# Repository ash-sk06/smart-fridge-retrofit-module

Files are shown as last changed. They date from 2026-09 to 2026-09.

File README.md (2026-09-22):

<p align="center">
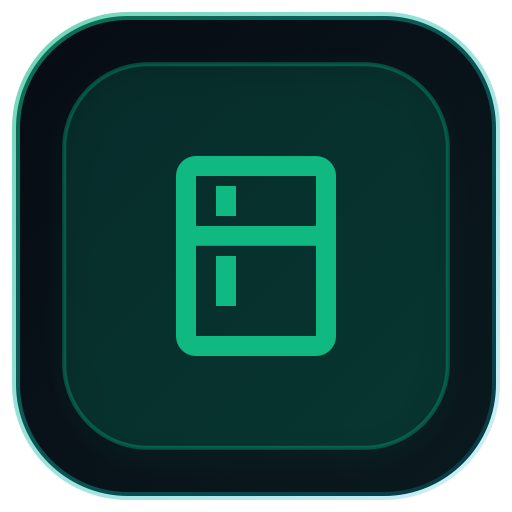
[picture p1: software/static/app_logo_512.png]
ChillSense Logo
  
</p>

# ChillSense — Smart Fridge Retrofit Module
### AI Refrigerator Retrofit Module Using Multi-Sensor Fusion & Cloud Vision for Food Inventory Management








---

## 📌 Overview

The **Smart Fridge Retrofit Module** (**ChillSense**) is a non-invasive, low-cost (₹2,000 – ₹3,000 INR / ~$25–$35 USD) hardware-software upgrade package designed to transform any conventional household refrigerator into an intelligent, cloud-connected inventory management appliance.

Commercial smart refrigerators retail at prohibitive price points ($2,000–$4,000 USD). This retrofit module achieves continuous liquid volume tracking inside opaque cartons, real-time shelf telemetry, condensation-free overhead image capture, and automated restocking notifications through **synchronized multi-sensor IoT fusion** and **Cloud YOLOv8 AI vision**.

---

## 🚀 Key Features

- **Anti-Fog Conical Camera Pod (`cad/`):**
  - Custom 3D-printable dual-part enclosure designed for 4°C humid refrigeration environments.
  - Features a 65° conical anti-fog optical baffle, internal flash isolation collar (eliminating optical lens flare), and magnetic mounting.
- **Embedded IoT Micro-Hub Firmware (`software/firmware/`):**
  - **ESP32-CAM (with Upgraded OV3660 3MP Sensor):** Door-switch interrupt triggered image capture with synchronized 100ms flash strobe, sending JPEG frames via HTTP POST to the cloud/server.
  - **ESP32 Sensor Hub (ESP32-WROOM-32 / ESP32-S2):** Samples dual HX711 24-bit differential ADCs across dedicated 5kg cantilever scale trays, DHT22 climate sensor (temperature & humidity), and MC-38 magnetic door reed switch.
- **Central Telemetry & Cloud Vision Engine (`software/`):**
  - Lightweight Python Flask backend with SQLite inventory audit trails and RESTful APIs.
  - **Cloud AI Vision:** Ultralytics YOLOv8n inference pipeline for item identification and bounding-box tagging.
  - Automated low-stock trigger and grocery reordering pipeline.
  - Cloud-ready architecture (deployable on Render, Railway, AWS, or local host).
- **Mobile Companion App (`mobile_app/`):**
  - Cross-platform Flutter application (Android/iOS) with industrial dark-theme HUD.
  - **Native Android Push Notifications:** Delivers heads-up sound & vibration alerts with item name and remaining volume when containers fall below 20%.
  - Dual-zone animated liquid fill gauge (Milk & Beverage).
  - 2×2 responsive telemetry metric grid (DHT22 climate, MC-38 door switch, HX711 shelf mass) optimized for mobile portrait view.
  - Built-in live interactive simulation controls for faculty demonstration.

---

## 📂 Repository Structure

```text
.
├── cad/                                # 3D CAD models & 3D printing specifications
│   ├── anti_fog_camera_pod.scad        # Parametric OpenSCAD design source
│   ├── camera_pod_main_body.stl        # 3D-printable camera housing
│   ├── camera_pod_back_lid.stl         # Snap-fit backplate with magnet wells
│   ├── camera_pod_3d_render.jpg        # Photorealistic CAD preview
│   ├── generate_stl.py                 # Automated STL build script
│   └── 3D_PRINTING_AND_SLICING_GUIDE.md# PETG/PLA slicer specifications
│
├── software/                           # Cloud backend server, APIs, and firmware
│   ├── server.py                       # Core Flask REST server & YOLOv8 CV pipeline
│   ├── requirements.txt                # Python dependencies
│   ├── run_server.sh                   # One-click startup script
│   ├── render.yaml & Procfile          # Cloud deployment configuration
│   ├── templates/                      # Web dashboard interface (HTML5 / Tailwind CSS)
│   └── firmware/                       # Embedded C++ Arduino firmware
│       ├── esp32_cam_strobe.ino        # ESP32-CAM strobe & capture client
│       └── esp32_sensor_hub.ino        # ESP32 multi-sensor telemetry client
│
├── mobile_app/                         # Flutter companion mobile application (ChillSense)
│   ├── lib/                            # Application source (Layered MVVM Architecture)
│   │   ├── models/                     # Telemetry, inventory & sensor data models
│   │   ├── services/                   # HTTP REST API client & native notifications
│   │   ├── widgets/                    # Responsive telemetry grid & liquid gauges
│   │   └── screens/                    # Dashboard, sensors & live review demo
│   ├── pubspec.yaml                    # Dart package dependencies
│   ├── ChillSense-v1.0-release.apk     # Production Android release APK
│   └── android/                        # Native Android build & notification manifests
│
└── README.md                           # Master project documentation
```

---

## 🛠️ Quick Start Guide

### 1. Run the Backend & Cloud Vision Server
```bash
cd software
python3 -m venv venv
source venv/bin/activate
pip install -r requirements.txt
python server.py
# Server runs at http://0.0.0.0:5050 with live Web HUD
```

### 2. Build or Install the Mobile App
```bash
cd mobile_app
flutter pub get
flutter run
# Or build production APK:
flutter build apk --release
```
*A pre-compiled production APK is also provided in `mobile_app/ChillSense-v1.0-release.apk`.*

### 3. 3D Print the Enclosure
Open `cad/anti_fog_camera_pod.scad` in OpenSCAD or slice the pre-rendered STL files:
- `cad/camera_pod_main_body.stl`
- `cad/camera_pod_back_lid.stl`
- Recommended material: **PETG** (moisture and condensation resistant in 4°C environments).

### 4. Flash Embedded Firmware
1. Open `software/firmware/esp32_sensor_hub.ino` and `software/firmware/esp32_cam_strobe.ino` in Arduino IDE.
2. Configure local Wi-Fi credentials and the server host address.
3. Flash to the respective ESP32 boards.

---

## 📜 Intellectual Property Framework

- **Inventive Step:** Event-Gated Differential Gravimetric Sampling & Anti-Fog Optical Enclosure for Retrofit Smart Refrigeration.
- **Core Problem Solved:** Eliminates load-cell thermal resistance drift across refrigeration temperature cycles through door-transit baseline calibration, while accurately quantifying fluid depletion inside opaque packaging without internal food immersion probes.
- Drafted in accordance with the **Indian Patents Act, 1970 (Form 2)**.

---

## 👥 Authors & Academic Context
Developed as an engineering capstone project focusing on sustainable embedded systems, Cloud AI vision, and household food waste reduction.

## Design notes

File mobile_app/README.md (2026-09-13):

# Smart Fridge Retrofit: Mobile Companion App (Flutter)
**Project:** AI Refrigerator Retrofit Module Using Multi-Sensor Fusion  
**Framework:** Flutter (Material 3)  
**Supported Platforms:** Android, iOS, Web (Chrome)

---

## 1. Features Overview

* **Real-Time Dual-Zone Fill Gauges:** Live animated liquid gradient bars showing milliliters ($ml$) and percentage ($%$) remaining for milk (Zone 1) and orange juice (Zone 2).
* **Dynamic Low-Stock Warnings:** Color-coded indicators:
  * **Green (Optimal):** $\ge 45\%$ fill
  * **Amber (Moderate):** $20\% - 44\%$ fill
  * **Red (Low Stock):** $< 20\%$ fill (triggers auto-shopping list insertion)
* **Live Environmental Telemetry:** Real-time monitoring of internal fridge temperature ($^\circ\text{C}$), relative humidity ($\% \text{RH}$), and door state (`OPEN` / `CLOSED`).
* **Overhead Vision AI Feed:** Displays the latest snapshot taken by the ESP32-CAM when the door was last closed, along with YOLOv8 detection tags (`bottle (Dairy)`, etc.).
* **Smart Automated Grocery List:** Automatically populates when liquid drops below $20\%$. Features interactive checkboxes to cross off items while shopping.
* **Faculty Review Demo Sandbox:** Floating action button with one-tap simulated events ("Pour 150ml Milk", "Toggle Door Event", "Trigger Low Stock Alert") to demonstrate dynamic UI updates during viva/reviews even without hardware powered on.

---

## 2. Quick Start: Running the App

### Step 1: Start Your Flask Backend on Your Laptop
In your terminal, launch the server:
```bash
cd "/Users/ashwathsathish/Library/Mobile Documents/com~apple~CloudDocs/AI Refridgerator Retrofit Module/software"
python3 server.py
```
Find your laptop's local IP address:
* **macOS / Linux:** Run `ifconfig | grep "inet "` (look for `192.168.x.x` or `10.x.x.x`).
* **Windows:** Run `ipconfig` (look for `IPv4 Address`).

### Step 2: Open & Run the Flutter App
Make sure your phone and laptop are on the **same Wi-Fi network or Mobile Hotspot**.

#### Option A: Run Directly on Your Android Phone (USB Debugging)
1. Enable **Developer Options** and **USB Debugging** on your Android phone.
2. Connect your phone to your laptop via USB cable.
3. Open a terminal in the `mobile_app/` folder:
   ```bash
   cd mobile_app
   flutter pub get
   flutter run
   ```
4. Once the app launches on your phone, tap the **Settings icon** (top right) and enter your laptop's IP address (e.g. `192.168.1.105:5000`).

#### Option B: Run in Chrome / Browser (Zero Phone Setup)
If you don't have an Android device plugged in, you can run the app directly in your desktop browser:
```bash
cd mobile_app
flutter pub get
flutter run -d chrome
```

#### Option C: Build the Standalone Android APK (To Share With Teammates)
To generate an installable `.apk` file:
```bash
cd mobile_app
flutter build apk --release
```
The installable APK will be created at:  
`mobile_app/build/app/outputs/flutter-apk/app-release.apk`  
You can send this APK to your teammates via WhatsApp or Google Drive and install it on any Android phone!

---

## 3. Directory Structure

```
mobile_app/
├── pubspec.yaml               # Flutter package configuration
├── README.md                  # This build & user guide
└── lib/
    ├── main.dart              # App entry point with Material 3 theme
    ├── models/
    │   └── inventory_model.dart  # Parsers for inventory, telemetry & shopping list
    ├── services/
    │   └── api_service.dart      # HTTP REST client communicating with Flask
    ├── widgets/
    │   ├── liquid_gauge_card.dart  # Animated liquid progress bar & metrics
    │   ├── telemetry_header.dart   # Live door, temp & humidity status
    │   ├── shopping_list_card.dart # Automated grocery list with checkboxes
    │   └── camera_vision_card.dart # ESP32-CAM overhead photo & YOLO tags
    └── screens/
        └── home_screen.dart       # Main dashboard with auto-polling & demo sandbox
```

---

## 4. Viva / Review Demonstration Script

When presenting to your faculty guide:
1. **Show the live connection:** Point out the green **"ESP32 HUB LIVE"** pill and the real-time temperature ($4.1^\circ\text{C}$).
2. **Demonstrate liquid depletion:** 
   * Lift a carton off the dual load-cell tray (or tap **"Pour 150ml Milk"** in the Demo Sandbox).
   * Within 2 seconds, watch the **liquid gauge drop** from $1000\text{ ml}$ to $850\text{ ml}$ on your phone in real-time.
3. **Demonstrate the automated trigger:**
   * Tap **"Trigger Low Stock Alert (< 20%)"**.
   * Show how the gauge turns **red**, the status changes to `LOW STOCK`, and the item **instantly appears on the Smart Shopping List** at the bottom of the screen.
4. **Demonstrate the door alarm:**
   * Open the mock fridge door (or tap **"Toggle Door Event"**).
   * Show the header flash yellow/red: **`DOOR OPEN`**.

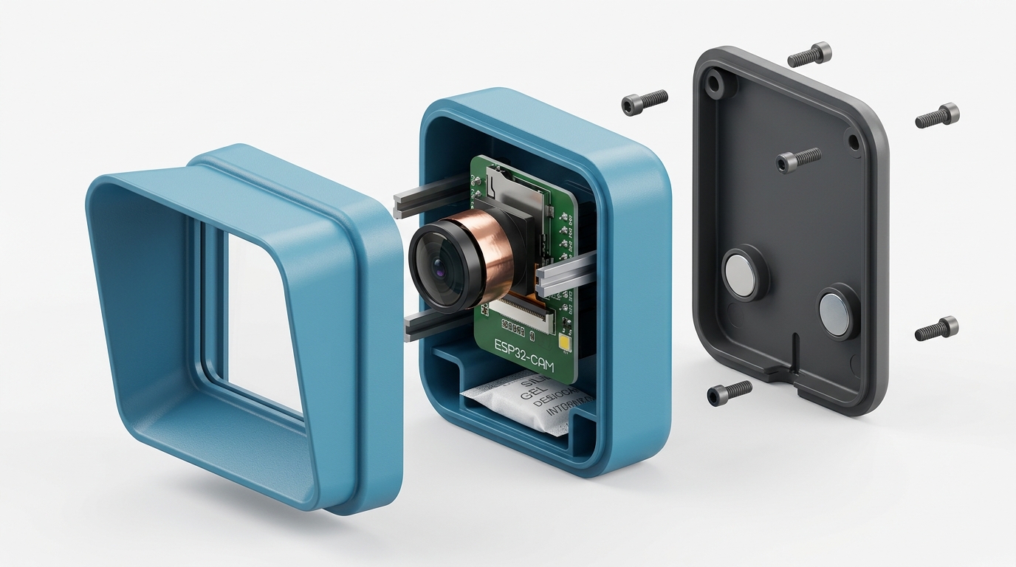
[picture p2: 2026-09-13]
cad/camera_pod_3d_render.jpg

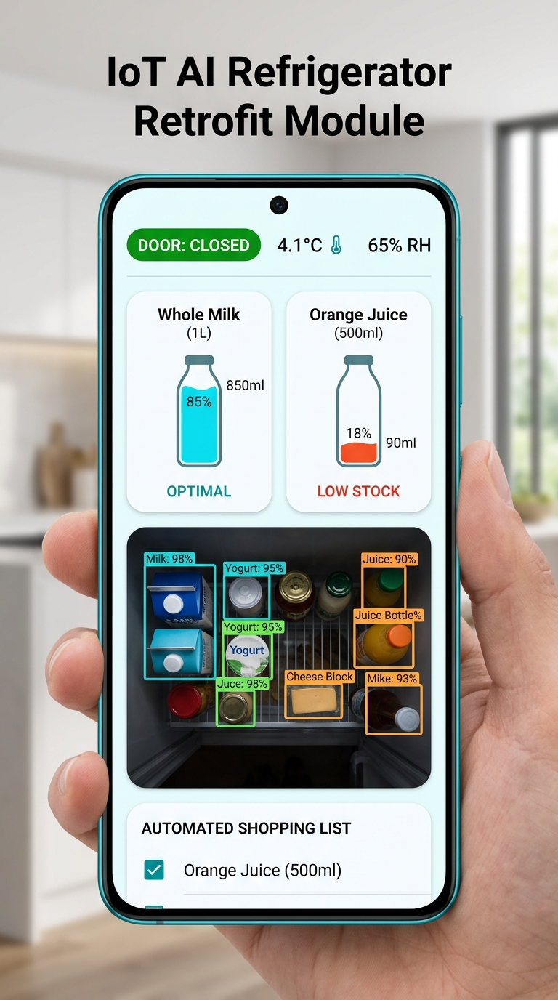
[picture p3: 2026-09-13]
mobile_app/mobile_app_ui_mockup.jpg

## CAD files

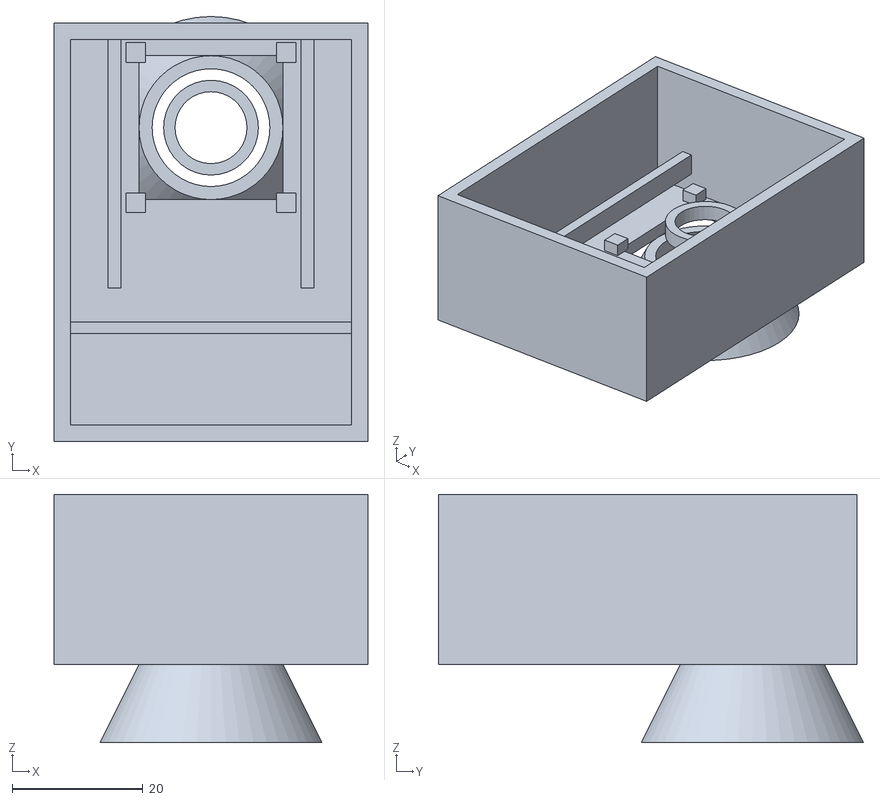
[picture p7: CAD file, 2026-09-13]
cad/camera_pod_main_body.stl
48.0 x 65.0 x 38.0

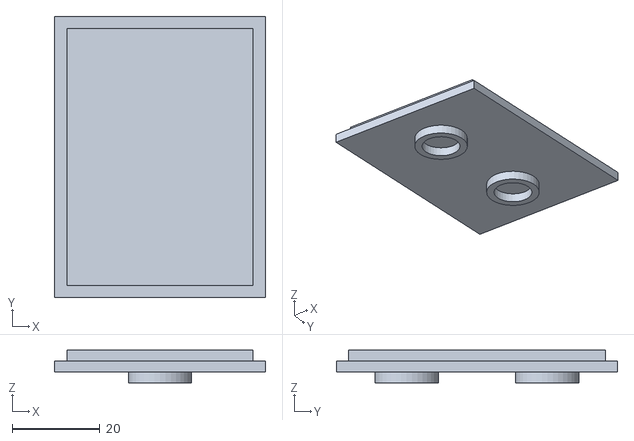
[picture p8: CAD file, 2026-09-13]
cad/camera_pod_back_lid.stl
48.0 x 64.0 x 7.50

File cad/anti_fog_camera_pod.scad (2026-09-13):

// =============================================================================
// AI REFRIGERATOR RETROFIT MODULE: 2-PART ANTI-FOG OPTIMIZED CAMERA POD
// Project: Dual-Zone Multi-Sensor Food Inventory System
// Target Hardware: AI-Thinker ESP32-CAM (OV2640 Module)
// Optical Upgrades:
//   1. 65-Degree Conical Flared Baffle (Zero Corner Vignetting / No Cut-Off)
//   2. Internal Optical Isolation Collar (Zero Flash LED Glare Bleed / No Milky Glare)
//   3. Retains Parasitic Heat Channel (Patent Claim 3) & Desiccant Bay
// =============================================================================

$fn = 60; // Smooth circular curves for 3D printing

// -----------------------------------------------------------------------------
// USER CONFIGURATION / DIMENSIONAL PARAMETERS (All dimensions in mm)
// -----------------------------------------------------------------------------
wall_th = 2.5;                // Structural wall thickness
box_w = 48.0;                 // Outer width
box_h = 64.0;                 // Outer height
box_d = 26.0;                 // Outer depth of cavity body

// Optical Aperture & Conical Anti-Fog Baffle
baffle_len = 12.0;            // 12mm forward extension for stagnant dead-air zone
baffle_base_id = 18.0;        // Inner diameter at optical window
baffle_mouth_id = 30.0;       // Flared inner diameter at mouth (accommodates 66° FOV cone)
baffle_wall = 2.0;            // Wall thickness of the baffle cone
lens_y_offset = 16.0;         // Offset from top edge to camera optical center

// Internal Optical Isolation Collar (Isolates Lens from Flash LED)
collar_id = 11.0;             // Inner diameter (clears 8.5mm OV2640 lens)
collar_od = 14.5;             // Outer diameter (physically blocks adjacent flash LED)
collar_h = 2.8;               // Extends backward to meet OV2640 sensor face

// Acrylic Optical Window Retention Pocket (Internal)
window_w = 26.0;              // Square pocket for 25x25mm acrylic square (+1mm clearance)
window_h = 26.0;              // Square pocket height
window_th = 2.2;              // Pocket depth for standard 2.0mm acrylic pane

// ESP32-CAM Module (AI-Thinker Standard: 27.0mm x 40.5mm)
pcb_w = 27.5;                 // PCB slot width (+0.5mm slide clearance)
pcb_th = 1.6;                 // Standard FR4 PCB thickness
pcb_h = 40.5;                 // PCB height

// Desiccant Bay (Silica Gel 1g-2g Pouch)
desiccant_w = 40.0;
desiccant_h = 14.0;
desiccant_d = 18.0;

// Back Lid & Magnetic Retrofit Mounts
lid_th = 2.5;
magnet_diam = 10.3;           // Sized for standard 10mm Neodymium disc magnets
magnet_depth = 2.2;           // Depth for 2mm thick disc magnets
cable_diam = 4.5;             // Micro-USB / power cable diameter

// -----------------------------------------------------------------------------
// SELECT WHAT TO RENDER (Change number to render specific part)
// 1 = Complete 2-Part Exploded Assembly (Visualization)
// 2 = Part 1: Main Housing with Flared Baffle & Light Collar (Print 1x)
// 3 = Part 2: Back Lid with Magnetic Mounts (Print 1x)
// -----------------------------------------------------------------------------
RENDER_PART = 1;

if (RENDER_PART == 1) {
    exploded_assembly_2part();
} else if (RENDER_PART == 2) {
    part1_main_housing_integrated();
} else if (RENDER_PART == 3) {
    part2_back_lid();
}

// =============================================================================
// PART 1: MAIN HOUSING WITH CONICAL BAFFLE & OPTICAL ISOLATION COLLAR
// =============================================================================
module part1_main_housing_integrated() {
    union() {
        // --- Main Housing Body ---
        difference() {
            // Outer Rounded Box
            hull() {
                translate([2, 2, 0]) cylinder(r=2, h=box_d);
                translate([box_w - 2, 2, 0]) cylinder(r=2, h=box_d);
                translate([box_w - 2, box_h - 2, 0]) cylinder(r=2, h=box_d);
                translate([2, box_h - 2, 0]) cylinder(r=2, h=box_d);
            }

            // Main Internal Cavity
            translate([wall_th, wall_th, wall_th])
                cube([box_w - 2 * wall_th, box_h - 2 * wall_th, box_d]);

            // Optical Aperture Through Front Face
            translate([box_w / 2, box_h - lens_y_offset, -1])
                cylinder(d=baffle_base_id, h=wall_th + 2);

            // Acrylic Window Retention Recess (Inside front wall: 26x26x2.2mm)
            translate([(box_w - window_w) / 2, (box_h - lens_y_offset) - window_h / 2, wall_th - window_th + 0.01])
                cube([window_w, window_h, window_th + 0.1]);

            // Parasitic Thermal Conduction Channel (Claim 3)
            translate([(box_w - 12) / 2, (box_h - lens_y_offset) - window_h / 2 - 10, wall_th - 1.2])
                cube([12, 12, 1.5]);

            // Rear Lid Inset Lip Chamfer
            translate([wall_th - 0.4, wall_th - 0.4, box_d - 2.5])
                cube([box_w - 2 * wall_th + 0.8, box_h - 2 * wall_th + 0.8, 3.0]);
        }

        // --- Integrated 65-Degree Conical Anti-Fog Baffle (Monolithic) ---
        // Flares outward from 18mm at the glass to 30mm at the mouth
        translate([box_w / 2, box_h - lens_y_offset, -baffle_len])
            difference() {
                // Outer tapered cone (63° angle from horizontal — 100% printable with NO supports)
                cylinder(d1=baffle_mouth_id + 2 * baffle_wall, d2=baffle_base_id + 2 * baffle_wall, h=baffle_len + 0.05);
                
                // Conical optical tunnel through-hole
                translate([0, 0, -1])
                    cylinder(d1=baffle_mouth_id, d2=baffle_base_id, h=baffle_len + 3);
            }

        // --- Internal Optical Isolation Collar (Blocks Flash LED Bleed) ---
        // Extends backwards from the acrylic window to hug the OV2640 lens barrel
        translate([box_w / 2, box_h - lens_y_offset, wall_th + window_th - 0.1])
            difference() {
                cylinder(d=collar_od, h=collar_h);
                translate([0, 0, -0.5])
                    cylinder(d=collar_id, h=collar_h + 1);
            }

        // --- Internal ESP32-CAM Guide Rails ---
        rail_x_left = (box_w - pcb_w) / 2 - 2.0;
        rail_x_right = (box_w + pcb_w) / 2;
        rail_y_start = box_h - wall_th - pcb_h - 1.0;
        rail_z_pos = wall_th + window_th + 2.0; // Keeps OV2640 lens 2mm behind acrylic

        difference() {
            union() {
                // Left Guide Rail
                translate([rail_x_left, rail_y_start, rail_z_pos - 1])
                    cube([2.0, pcb_h, 5.0]);
                // Right Guide Rail
                translate([rail_x_right, rail_y_start, rail_z_pos - 1])
                    cube([2.0, pcb_h, 5.0]);

                // Bottom Desiccant Bay Separator Rib
                translate([wall_th, wall_th + desiccant_h, wall_th])
                    cube([box_w - 2 * wall_th, 1.8, 12.0]);
            }
            // Slot for PCB to slide into smoothly
            translate([(box_w - pcb_w) / 2, rail_y_start - 1, rail_z_pos])
                cube([pcb_w, pcb_h + 2, pcb_th + 0.4]);
            
            // Air circulation cutout in desiccant rib
            translate([box_w / 2 - 8, wall_th + desiccant_h - 1, wall_th])
                cube([16, 4, 8]);
        }
    }
}

// =============================================================================
// PART 2: BACK LID WITH MAGNETIC RETROFIT MOUNTS & CABLE STRAIN RELIEF
// =============================================================================
module part2_back_lid() {
    difference() {
        union() {
            hull() {
                translate([2, 2, 0]) cylinder(r=2, h=lid_th);
                translate([box_w - 2, 2, 0]) cylinder(r=2, h=lid_th);
                translate([box_w - 2, box_h - 2, 0]) cylinder(r=2, h=lid_th);
                translate([2, box_h - 2, 0]) cylinder(r=2, h=lid_th);
            }

            translate([wall_th + 0.25, wall_th + 0.25, lid_th])
                cube([box_w - 2 * wall_th - 0.5, box_h - 2 * wall_th - 0.5, 2.5]);
        }

        // Dual 10mm Neodymium Magnet Recesses
        translate([box_w / 2, box_h * 0.28, -0.1])
            cylinder(d=magnet_diam, h=magnet_depth);
        translate([box_w / 2, box_h * 0.72, -0.1])
            cylinder(d=magnet_diam, h=magnet_depth);

        // Optional M3 Countersunk Screw Holes
        translate([box_w / 2, box_h * 0.28, -1])
            cylinder(d=3.4, h=lid_th + 5);
        translate([box_w / 2, box_h * 0.72, -1])
            cylinder(d=3.4, h=lid_th + 5);
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

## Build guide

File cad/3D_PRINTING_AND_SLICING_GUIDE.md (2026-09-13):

# 3D Printing & Assembly Guide: 2-Part Anti-Fog Camera Pod
**Project:** AI Refrigerator Retrofit Module Using Multi-Sensor Fusion  
**Target Hardware:** AI-Thinker ESP32-CAM (OV2640 Sensor)  
**Location:** [`cad/`](file:///Users/ashwathsathish/Library/Mobile%20Documents/com~apple~CloudDocs/AI%20Refridgerator%20Retrofit%20Module/cad/)

---

## 1. File Inventory (Strictly 2 Parts - Optically Optimized)

| File | Description | Material & Quantity |
| :--- | :--- | :---: |
| [**`camera_pod_main_body.stl`**](file:///Users/ashwathsathish/Library/Mobile%20Documents/com~apple~CloudDocs/AI%20Refridgerator%20Retrofit%20Module/cad/camera_pod_main_body.stl) | **Part 1:** Main housing with **$65^\circ$ conical flared baffle** (zero corner vignetting), **internal optical isolation collar** (stops flash LED bleed), $25\times25\text{ mm}$ acrylic pocket, ESP32 slide rails, and desiccant bay. | PLA / PETG (1x) |
| [**`camera_pod_back_lid.stl`**](file:///Users/ashwathsathish/Library/Mobile%20Documents/com~apple~CloudDocs/AI%20Refridgerator%20Retrofit%20Module/cad/camera_pod_back_lid.stl) | **Part 2:** Snap-fit rear cover with dual $10\text{ mm}$ Neodymium magnet sockets and S-curve cable strain relief. | PLA / PETG (1x) |
| [**`anti_fog_camera_pod.scad`**](file:///Users/ashwathsathish/Library/Mobile%20Documents/com~apple~CloudDocs/AI%20Refridgerator%20Retrofit%20Module/cad/anti_fog_camera_pod.scad) | Parametric OpenSCAD source file with 3D exploded assembly view. | Source |
| [**`generate_stl.py`**](file:///Users/ashwathsathish/Library/Mobile%20Documents/com~apple~CloudDocs/AI%20Refridgerator%20Retrofit%20Module/cad/generate_stl.py) | Python script to regenerate binary STLs directly. | Script |

---

## 2. 3D Slicer Settings (Cura / PrusaSlicer / Bambu Studio)

Both parts are engineered to print with **ZERO supports (0% supports needed)**.

```
┌────────────────────────────────────────────────────────────────────────┐
│                        RECOMMENDED SLICE PROFILE                       │
├─────────────────────────┬──────────────────────────────────────────────┤
│ Material                │ PETG (Preferred for cold/moisture) or PLA    │
│ Layer Height            │ 0.20 mm (Standard)                           │
│ Wall Line Count (Perim) │ 3 to 4 walls (≥ 1.2 mm solid perimeter)      │
│ Top / Bottom Layers     │ 4 top / 4 bottom layers                      │
│ Infill Density          │ 20%                                          │
│ Infill Pattern          │ Gyroid or Grid                               │
│ Print Speed             │ 50 mm/s                                      │
│ Supports                │ NONE (Disabled - 0% supports needed)         │
│ Build Plate Adhesion    │ Skirt (or 3mm Brim if bed adhesion is weak)  │
│ Bed Temperature         │ PLA: 60°C | PETG: 75°C - 80°C                │
│ Nozzle Temperature      │ PLA: 205°C | PETG: 235°C - 240°C             │
└─────────────────────────┴──────────────────────────────────────────────┘
```

### Print Orientation by Part:
1. **`camera_pod_main_body.stl`**: Place flat on its front face (baffle tube rim resting down on the build plate).
2. **`camera_pod_back_lid.stl`**: Place flat with the exterior face down on the bed.

### Print Statistics:
* **Total Filament Weight:** ~32 grams (~₹25 INR of filament).
* **Total Print Time:** ~1 hour 15 minutes on an Ender-3; ~25 minutes on a Bambu / K1.

---

## 3. Physical Assembly Steps

```
Step 1: Drop in Acrylic Window (25x25x2mm) from inside into molded pocket.
Step 2: Attach Foil Thermal Ribbon to ESP32 RF shield & route to window edge.
Step 3: Slide ESP32-CAM PCB into internal guide rails (lens 2mm behind window).
Step 4: Place 1g Silica Gel Pouch in the bottom bay.
Step 5: Press 2x 10mm Neodymium Magnets into back lid & snap lid shut.
Step 6: Buff outer acrylic face with half a drop of dish soap (surfactant film).
```

### Detailed Assembly:
1. **Optical Window:** Cut a $25\text{ mm} \times 25\text{ mm}$ square from 2.0mm clear acrylic (or scrap CD jewel case). Clean with alcohol, drop into the internal pocket behind the baffle, and seal edges with 2 drops of hot glue or silicone.
2. **Parasitic Heat Conductor (Claim 3):** Tape a strip of folded kitchen aluminum foil (or copper tape) to the ESP32's silver metal shield. Route it to touch the edge of the acrylic pane.
3. **Slide Board In:** Slide the ESP32-CAM (27.0mm wide) into the molded rails. The OV2640 lens sits centered directly behind the optical aperture.
4. **Desiccant:** Drop a 1g silica gel sachet into the lower compartment.
5. **Magnetic Mount:** Press two $10\text{ mm} \times 2\text{ mm}$ Neodymium magnets into the back lid sockets. Route the power cable through the strain-relief slot and press the lid shut!

---

## 4. Outer Hydrophilic Coating Application

Before sticking the pod inside the refrigerator:
1. Put half a drop of liquid dish soap (**Vim / Pril / Colin**) onto the outer face of the acrylic window (inside the baffle cone).
2. Spread evenly with a cotton bud. Let dry for 60 seconds.
3. Buff vigorously with a clean, dry microfiber cloth until completely transparent.
4. Water condensation will now form a flat transparent liquid sheet (contact angle $< 10^\circ$) instead of scattering droplets.

---

## 5. Critical Lens Macro Focus Adjustment (25 cm Shelf Height)

> [!IMPORTANT]
> **Why this is necessary:** All stock OV2640 modules from the factory are pre-focused at **1 meter to infinity**. At the 22–25 cm distance inside a refrigerator, the food cartons and labels will be slightly blurry unless you perform this 10-second adjustment:

1. Look at the threaded circular lens barrel on the OV2640 sensor. There is a tiny dot of yellow glue locking the thread.
2. Use tweezers or a hobby knife to gently pick away the glue dot.
3. Power up the ESP32-CAM and open the live stream on your laptop screen.
4. Hold a milk or juice carton **$25\text{ cm}$ away**.
5. Slowly rotate the lens barrel **counter-clockwise by approximately $60^\circ\text{ to }90^\circ$ (about a 1/4 turn)**.
6. The carton text and barcode will snap into razor-sharp macro focus!

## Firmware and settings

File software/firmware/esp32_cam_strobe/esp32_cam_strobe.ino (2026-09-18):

/*
 * AI REFRIGERATOR RETROFIT MODULE - OVERHEAD FLASH CAMERA POD
 * Target Board: AI-Thinker ESP32-CAM (with Upgraded OV3660 3MP / OV2640 Sensor)
 * Function: Enclosed flash strobe & HTTP multipart image upload
 */

#include "esp_camera.h"
#include <WiFi.h>
#include <HTTPClient.h>

// --- PIN DEFINITIONS FOR AI THINKER ESP32-CAM ---
#define PWDN_GPIO_NUM     32
#define RESET_GPIO_NUM    -1
#define XCLK_GPIO_NUM      0
#define SIOD_GPIO_NUM     26
#define SIOC_GPIO_NUM     27
#define Y9_GPIO_NUM       35
#define Y8_GPIO_NUM       34
#define Y7_GPIO_NUM       39
#define Y6_GPIO_NUM       36
#define Y5_GPIO_NUM       21
#define Y4_GPIO_NUM       19
#define Y3_GPIO_NUM       18
#define Y2_GPIO_NUM        5
#define VSYNC_GPIO_NUM    25
#define HREF_GPIO_NUM     23
#define PCLK_GPIO_NUM     22

#define FLASH_LED_PIN      4  // High-Power Onboard White Flash LED

// --- NETWORK CONFIGURATION ---
const char* ssid = "YOUR_HOTSPOT_OR_WIFI_NAME";
const char* password = "YOUR_HOTSPOT_PASSWORD";
// Set to your laptop's Local IP
const char* serverUrl = "http://192.168.1.23:5050/api/upload-image";

void setup() {
  Serial.begin(115200);
  pinMode(FLASH_LED_PIN, OUTPUT);
  digitalWrite(FLASH_LED_PIN, LOW);

  camera_config_t config;
  config.ledc_channel = LEDC_CHANNEL_0;
  config.ledc_timer = LEDC_TIMER_0;
  config.pin_d0 = Y2_GPIO_NUM;
  config.pin_d1 = Y3_GPIO_NUM;
  config.pin_d2 = Y4_GPIO_NUM;
  config.pin_d3 = Y5_GPIO_NUM;
  config.pin_d4 = Y6_GPIO_NUM;
  config.pin_d5 = Y7_GPIO_NUM;
  config.pin_d6 = Y8_GPIO_NUM;
  config.pin_d7 = Y9_GPIO_NUM;
  config.pin_xclk = XCLK_GPIO_NUM;
  config.pin_pclk = PCLK_GPIO_NUM;
  config.pin_vsync = VSYNC_GPIO_NUM;
  config.pin_href = HREF_GPIO_NUM;
  config.pin_sscb_sda = SIOD_GPIO_NUM;
  config.pin_sscb_scl = SIOC_GPIO_NUM;
  config.pin_pwdn = PWDN_GPIO_NUM;
  config.pin_reset = RESET_GPIO_NUM;
  config.xclk_freq_hz = 20000000;
  config.pixel_format = PIXFORMAT_JPEG;
  config.frame_size = FRAMESIZE_VGA; // 640x480 (Ideal for edge YOLO)
  config.jpeg_quality = 12;          // 0-63 (Lower = higher quality)
  config.fb_count = 1;

  // Initialize Camera
  esp_err_t err = esp_camera_init(&config);
  if (err != ESP_OK) {
    Serial.printf("[!] Camera init failed with error 0x%x\n", err);
    return;
  }
  sensor_t *s = esp_camera_sensor_get();
  if (s != NULL) {
    // OV3660 auto-detected: calibrate orientation and brightness for dark fridge interior
    s->set_vflip(s, 1);        // Set to 1 if image orientation is inverted
    s->set_brightness(s, 1);   // Optimal exposure for 100ms flash strobe
    Serial.println("[OK] Camera Sensor Initialized (OV3660 / OV2640 auto-detected).");
  }

  // Connect to Wi-Fi
  WiFi.begin(ssid, password);
  while (WiFi.status() != WL_CONNECTED) {
    delay(500);
    Serial.print(".");
  }
  Serial.println("\n[OK] ESP32-CAM Wi-Fi Connected. IP: " + WiFi.localIP().toString());
}

void captureAndSend() {
  Serial.println("[*] Triggering Enclosed Flash Strobe...");
  digitalWrite(FLASH_LED_PIN, HIGH); // Flash ON
  delay(100);                         // 100ms exposure window

  camera_fb_t *fb = esp_camera_fb_get();
  digitalWrite(FLASH_LED_PIN, LOW);  // Flash OFF

  if (!fb) {
    Serial.println("[!] Camera capture failed!");
    return;
  }

  Serial.printf("[*] Image captured: %d bytes. Uploading to server...\n", fb->len);

  if (WiFi.status() == WL_CONNECTED) {
    HTTPClient http;
    http.begin(serverUrl);

    String boundary = "----WebKitFormBoundary7MA4YWxkTrZu0gW";
    http.addHeader("Content-Type", "multipart/form-data; boundary=" + boundary);

    String bodyStart = "--" + boundary + "\r\n" +
                       "Content-Disposition: form-data; name=\"image\"; filename=\"capture.jpg\"\r\n" +
                       "Content-Type: image/jpeg\r\n\r\n";
    String bodyEnd = "\r\n--" + boundary + "--\r\n";

    int totalLen = bodyStart.length() + fb->len + bodyEnd.length();
    uint8_t *payload = (uint8_t *)malloc(totalLen);
    memcpy(payload, bodyStart.c_str(), bodyStart.length());
    memcpy(payload + bodyStart.length(), fb->buf, fb->len);
    memcpy(payload + bodyStart.length() + fb->len, bodyEnd.c_str(), bodyEnd.length());

    int httpCode = http.POST(payload, totalLen);
    Serial.printf("[*] Upload HTTP Response: %d\n", httpCode);

    free(payload);
    http.end();
  }

  esp_camera_fb_return(fb);
}

void loop() {
  // Listen for serial trigger or timed capture
  if (Serial.available()) {
    char cmd = Serial.read();
    if (cmd == 'c' || cmd == 'C') {
      captureAndSend();
    }
  }
  delay(100);
}

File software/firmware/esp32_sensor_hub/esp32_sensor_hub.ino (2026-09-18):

/*
 * AI REFRIGERATOR RETROFIT MODULE - DUAL-ZONE SENSOR HUB
 * Target Board: ESP32-S2-DevKitM-1 (Single-Core Xtensa LX7 @ 240MHz, 2.4GHz Wi-Fi)
 * Arduino IDE Board: "ESP32S2 Dev Module" or "ESP32-S2-DevKitM-1"
 * Hardware: 2x 5kg Pre-Fabricated Cantilever Load Cell Kits with HX711 ADCs, MC-38 Reed Switch, DHT11/DHT22
 */

#include "HX711.h"
#include <WiFi.h>
#include <HTTPClient.h>
#include "DHT.h"

// --- PIN CONFIGURATION (OPTIMIZED FOR ESP32-S2) ---
const int REED_PIN = 14;     // Door Reed Switch (INPUT_PULLUP, other pin to GND)
const int DT_DAIRY = 16;     // HX711 #1 (Dairy Zone 1 Data)
const int DT_DRINKS = 17;    // HX711 #2 (Beverage Zone 2 Data)
const int SCK_PIN = 4;       // Shared Clock Pulse for both HX711s
const int DHT_PIN = 5;       // DHT11/DHT22 Climate Data Pin (Safe GPIO on ESP32-S2)

// --- NETWORK CONFIGURATION ---
const char* ssid = "YOUR_HOTSPOT_OR_WIFI_NAME";
const char* password = "YOUR_HOTSPOT_PASSWORD";
// Set to your laptop's Local IP (Run 'ipconfig' on Windows or 'ifconfig' on Mac)
const char* serverUrl = "http://192.168.1.23:5050/api/sensor-event";

// --- OBJECT INSTANTIATIONS ---
HX711 scale_dairy;
HX711 scale_drinks;
DHT dht(DHT_PIN, DHT11);

// State tracking variables
float W0_dairy = 0.0;
float W0_drinks = 0.0;
bool wasDoorOpen = false;

void setup() {
  Serial.begin(115200);
  pinMode(REED_PIN, INPUT_PULLUP);
  dht.begin();

  // Initialize Dual-Zone Load Cells
  scale_dairy.begin(DT_DAIRY, SCK_PIN);
  scale_drinks.begin(DT_DRINKS, SCK_PIN);

  // Calibrate each zone using a standard 500g water bottle
  scale_dairy.set_scale(420.0);   // Adjust during calibration
  scale_drinks.set_scale(415.0);  // Adjust during calibration

  scale_dairy.tare();
  scale_drinks.tare();
  Serial.println("\n[OK] Dual-Zone Cantilever Scales Initialized and Tared.");

  // Connect to Wi-Fi
  Serial.print("[*] Connecting to Wi-Fi: ");
  Serial.println(ssid);
  WiFi.begin(ssid, password);
  while (WiFi.status() != WL_CONNECTED) {
    delay(500);
    Serial.print(".");
  }
  Serial.println("\n[OK] Wi-Fi Connected. Node IP: " + WiFi.localIP().toString());
}

void loop() {
  int doorState = digitalRead(REED_PIN); // HIGH = OPEN, LOW = CLOSED

  if (doorState == HIGH && !wasDoorOpen) {
    // PHASE 1: DOOR OPENED -> Latch baseline tare weights immediately
    wasDoorOpen = true;
    W0_dairy = scale_dairy.get_units(5);
    W0_drinks = scale_drinks.get_units(5);
    Serial.println("\n[!] Door OPENED -> Latched W0 (Dairy=" + String(W0_dairy, 1) + "g, Drinks=" + String(W0_drinks, 1) + "g)");
  } 
  else if (doorState == LOW && wasDoorOpen) {
    // PHASE 2: DOOR CLOSED -> Wait 1.2s damping delay for mechanical/liquid settling
    wasDoorOpen = false;
    Serial.println("\n[!] Door CLOSED -> Damping delay (1200ms)...");
    delay(1200); // Wait for liquid sloshing to settle

    // Read settled post-access mass (10-sample median filter)
    float W1_dairy = scale_dairy.get_units(10);
    float W1_drinks = scale_drinks.get_units(10);

    float delta_dairy = W1_dairy - W0_dairy;
    float delta_drinks = W1_drinks - W0_drinks;

    float temp = dht.readTemperature();
    if (isnan(temp)) temp = 4.1; // Default fallback if sensor unplugged

    Serial.println("==================================================");
    Serial.println("  POST-TRANSIT DUAL-ZONE MEASUREMENT ACQUIRED     ");
    Serial.println("  Zone 1 (Dairy): " + String(W1_dairy, 1) + "g (Delta: " + String(delta_dairy, 1) + "g)");
    Serial.println("  Zone 2 (Drinks): " + String(W1_drinks, 1) + "g (Delta: " + String(delta_drinks, 1) + "g)");
    Serial.println("  Compartment Temperature: " + String(temp, 1) + " °C");
    Serial.println("==================================================");

    // Transmit telemetry to Laptop Server
    sendTelemetry(W1_dairy, delta_dairy, W1_drinks, delta_drinks, temp, "CLOSED");
  }

  delay(50);
}

void sendTelemetry(float w_dairy, float d_dairy, float w_drinks, float d_drinks, float temp, String door) {
  if (WiFi.status() == WL_CONNECTED) {
    HTTPClient http;
    http.begin(serverUrl);
    http.addHeader("Content-Type", "application/json");

    String jsonPayload = "{"
      "\"zone1_weight\":" + String(w_dairy, 1) + ","
      "\"zone1_delta\":" + String(d_dairy, 1) + ","
      "\"zone2_weight\":" + String(w_drinks, 1) + ","
      "\"zone2_delta\":" + String(d_drinks, 1) + ","
      "\"temperature\":" + String(temp, 1) + ","
      "\"door\":\"" + door + "\""
    "}";

    int httpCode = http.POST(jsonPayload);
    Serial.println("[*] Telemetry POST Status: " + String(httpCode));
    http.end();
  } else {
    Serial.println("[!] Wi-Fi Disconnected. Telemetry could not be sent.");
  }
}

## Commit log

2026-09-13 feat: initial commit for Smart Fridge Retrofit Module
    Includes:
    - CAD: Parametric OpenSCAD design and STL models for anti-fog camera pod
    - Firmware: ESP32-CAM strobe client and ESP32 multi-sensor telemetry hub
    - Software: Flask REST backend with CV object detection and SQLite logging
    - Cloud: Render deployment specs and Procfile
    - Mobile App: Flutter companion app with dual-zone animated liquid gauge and telemetry
    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
    [anti_fog_camera_pod.scad, camera_pod_back_lid.stl, camera_pod_main_body.stl]
2026-09-18 refactor: update hardware specs and firmware for ESP32-S2-DevKitM-1, OV3660 3MP, and dual scale kits
2026-09-20 feat(ui,mobile): redesign FridgeIQ web dashboard and flutter companion app as hardware monitoring interfaces
    [server.py]
2026-09-22 fix(mobile): resolve pour 150ml bug, add prominent low stock trigger, and compile release APK
    [server.py]
2026-09-22 fix(mobile): resolve UI overflow in liquid card, header collision, and add local simulation for demo features
    [esp32_cam_strobe.ino, esp32_sensor_hub.ino]
2026-09-22 feat: fix door switch telemetry, add door-ajar (>45s) and cold-chain (>4.5°C) push alerts, and sync website logo
    [server.py]
